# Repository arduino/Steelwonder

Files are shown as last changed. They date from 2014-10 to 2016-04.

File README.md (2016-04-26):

Steelwonder
===========

This is the repository of the 3d printer that where built during a workshop hosted by Arduino LLC at the makerspace STPLN in Malmö, Sweden.

The frame [P3Steel](reprap.org/wiki/P3Steel) is a remix of [Twelvepro's](http://www.thingiverse.com/thing:39889/) redesign of [Josef Prusa's i3](https://github.com/josefprusa/Prusa3-vanilla). There have been some alterations to the frame such as the deletion of the triangles covering the xz frame and some holes for a powersupply and the electronics have been added. Also the printed parts have been borrowed from the box design from the current [Mendel Prusa i3 box design](https://github.com/josefprusa/Prusa3/tree/master/box_frame).

[Here] (http://youtu.be/In_Q6NkX3fs) you can find a video showing how to assemble the frame.

The plastic parts have mostly been sourced from the box design of the main Prusa i3 branch.

The shroud was sourced from [this](http://www.thingiverse.com/thing:165606) made by stratop80, also [available on tinkercad](https://tinkercad.com/things/1gkTvnWGP8F). Although it was revised and only used for inspiration.

The new plastic parts made for this machine:

  The shroud for the fan.
  
  The legs for the screen.

The Extras Folder.

There are some add-ons for the printer in this folder.

The source for the Y-endstop holder for the moving y-carriage can be found here [here] (https://www.youmagine.com/designs/y-endstop-support-for-p3steel) is made by Antonio Navarro.

An alternative to the shroud that was provided during the workshop is found [here] (http://www.thingiverse.com/thing:268372) and is made by Diego García.

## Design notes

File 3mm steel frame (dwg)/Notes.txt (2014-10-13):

The frame is meant to be cut in 3mm steel. 

The Update located in the "POSSIBLE_UPDATE" folder can also be found on thingiverse: http://www.thingiverse.com/thing:463371

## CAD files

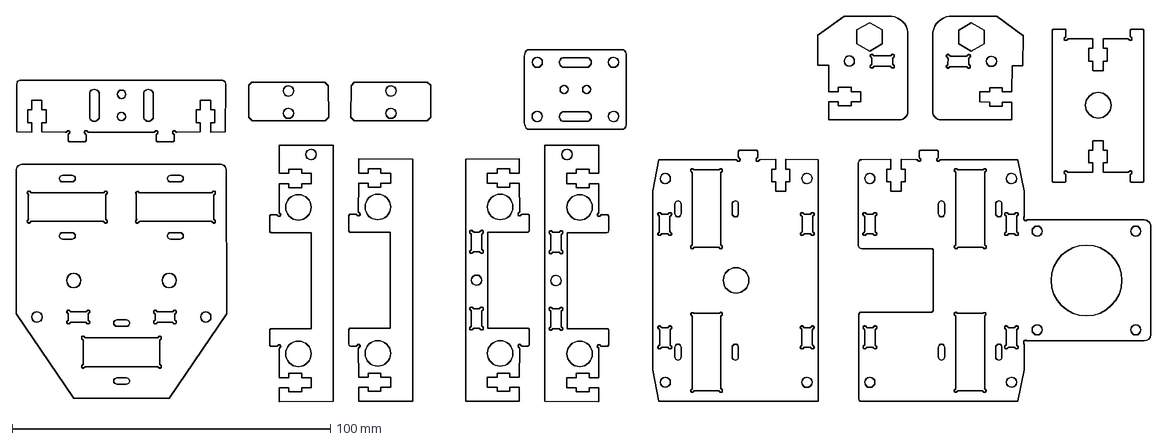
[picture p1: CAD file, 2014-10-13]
3mm steel frame (dwg)/POSSIBBLE_UPDATE/Leonardo_full_metal_cordobesa.dxf
356.4 x 121.1 mm

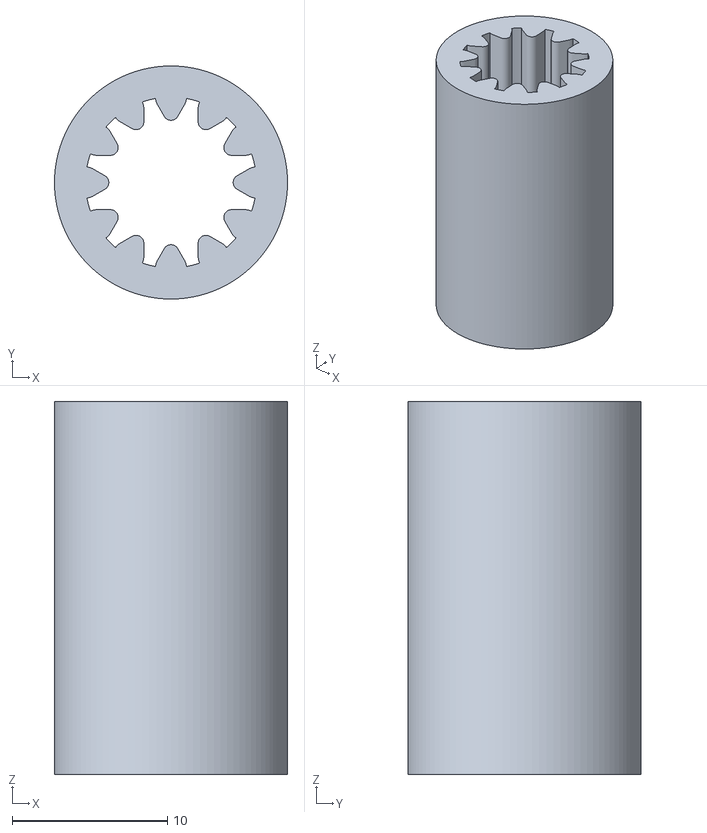
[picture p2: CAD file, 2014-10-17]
plastic parts (source)/OpenSCAD/includes/PrintableBearing_M8.stl
15.0 x 15.0 x 24.0

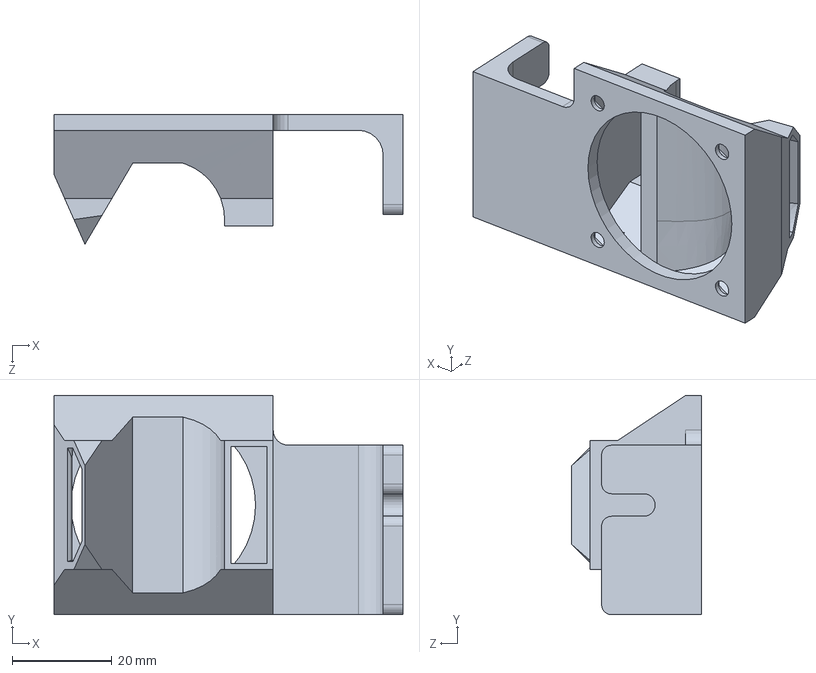
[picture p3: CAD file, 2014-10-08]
plastic parts (source)/Solidworks/Shroud/Shroud for Budaschnozzle.SLDPRT
70.0 x 44.0 x 26.0 mm

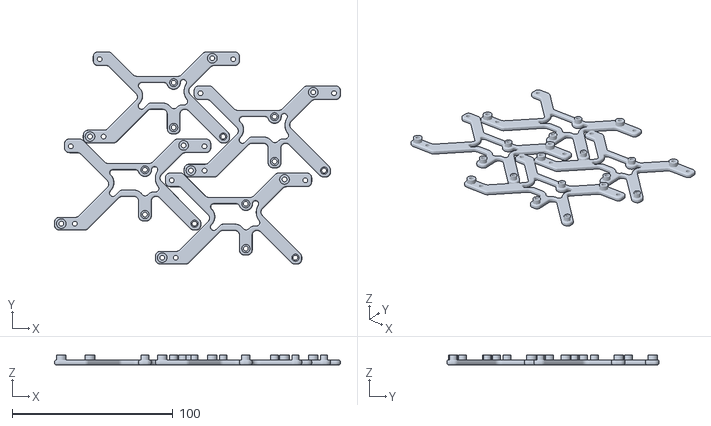
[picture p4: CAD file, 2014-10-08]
Plastic parts (stl)/Extras/Electronicsholder/holder - holder-1.STL
178.2 x 132.2 x 6.00

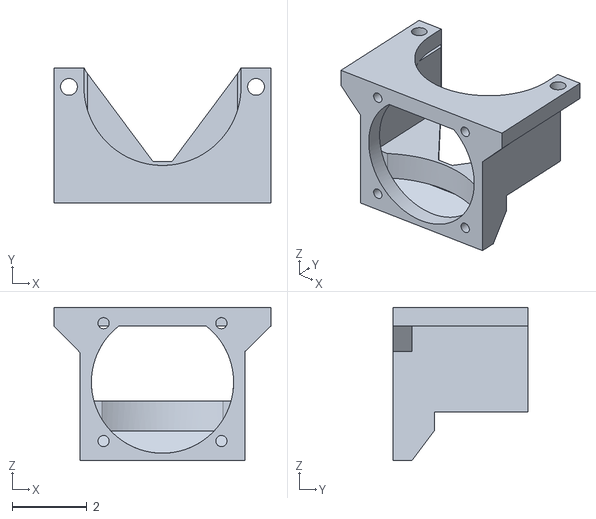
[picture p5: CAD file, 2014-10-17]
Plastic parts (stl)/Extras/Hot-end cooling mechanism/budasnozzle_soporte_ventilador_V2.stl
5.80 x 3.60 x 4.10

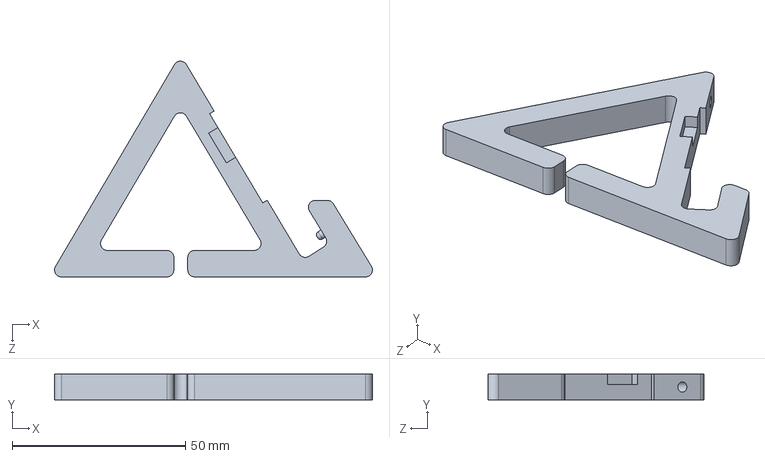
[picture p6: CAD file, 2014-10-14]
Plastic parts (stl)/Screen holder/3angle.SLDPRT
91.9 x 7.50 x 62.4 mm

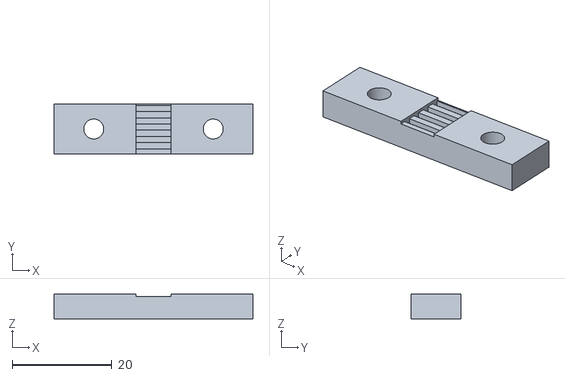
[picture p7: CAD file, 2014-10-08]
Plastic parts (stl)/Y-belt holder/y-holder-back.stl
40.0 x 10.0 x 5.00

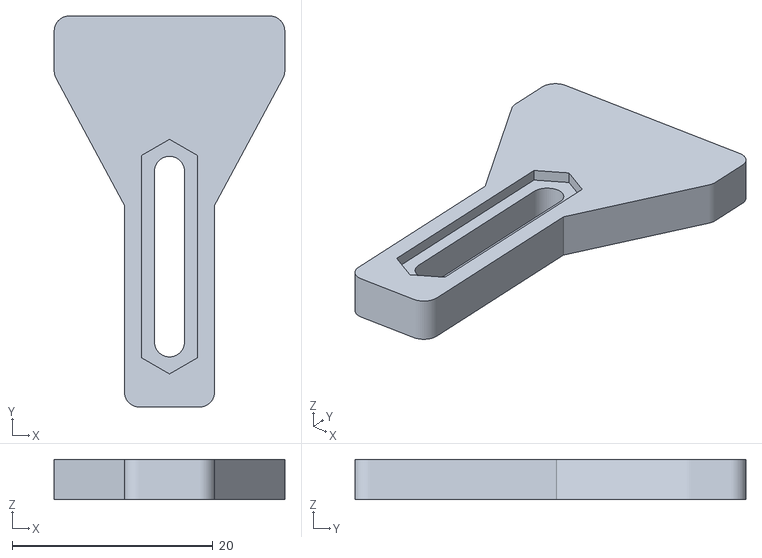
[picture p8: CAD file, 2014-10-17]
Plastic parts (stl)/Y-Endstop holders for y-carriage/P3Steel-Y-EndStop_part1.stl
23.0 x 39.0 x 4.00

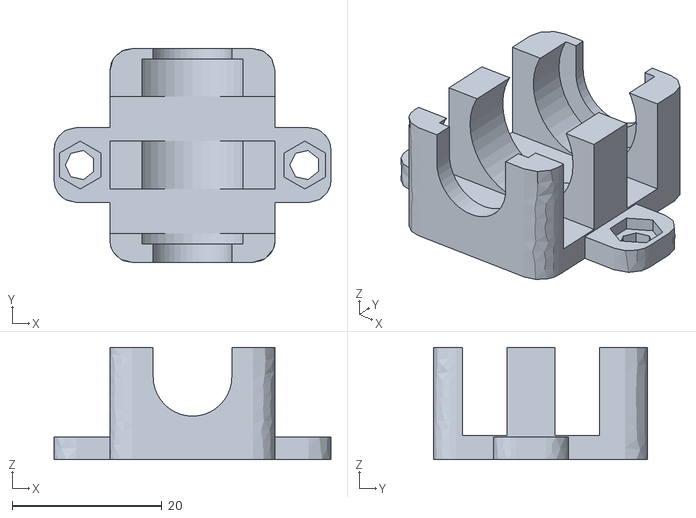
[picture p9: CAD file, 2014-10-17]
plastic parts (source)/OpenSCAD/includes/Pieza_Final (Meshed).stl
37.0 x 28.6 x 15.0

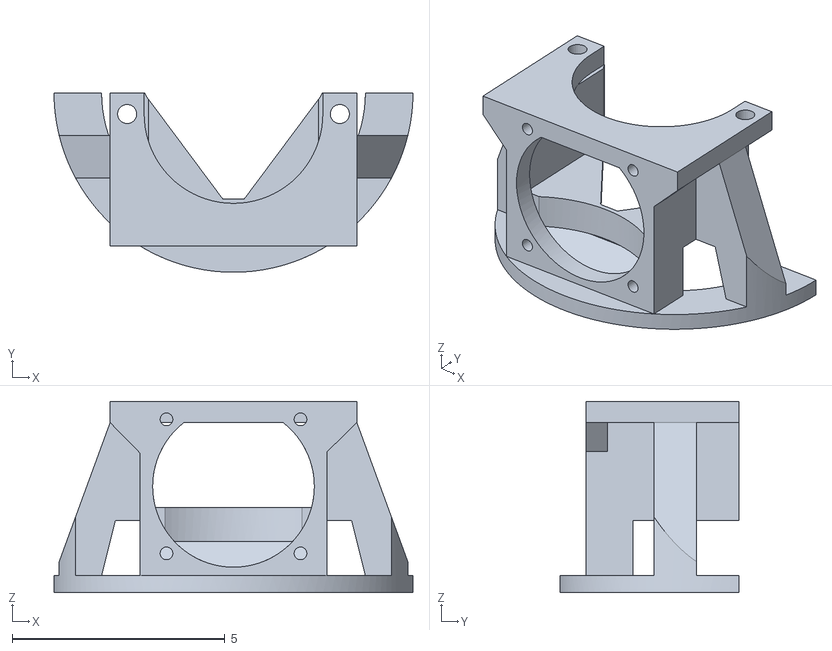
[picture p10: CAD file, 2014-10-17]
Plastic parts (stl)/Extras/Hot-end cooling mechanism/Budas_Ventilador_y_leds.stl
8.44 x 4.22 x 4.50

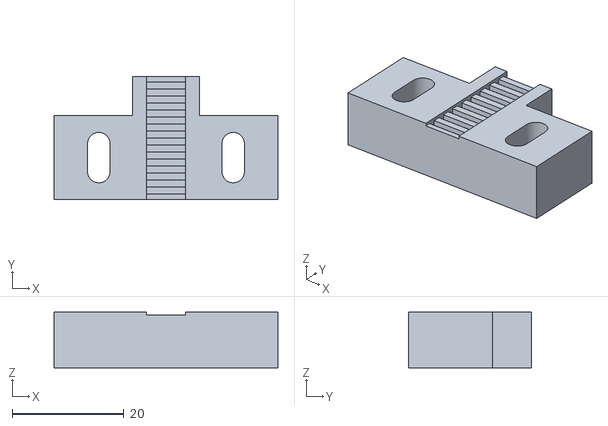
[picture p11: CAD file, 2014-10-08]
Plastic parts (stl)/Y-belt holder/y-holder-front.stl
40.0 x 22.0 x 10.0

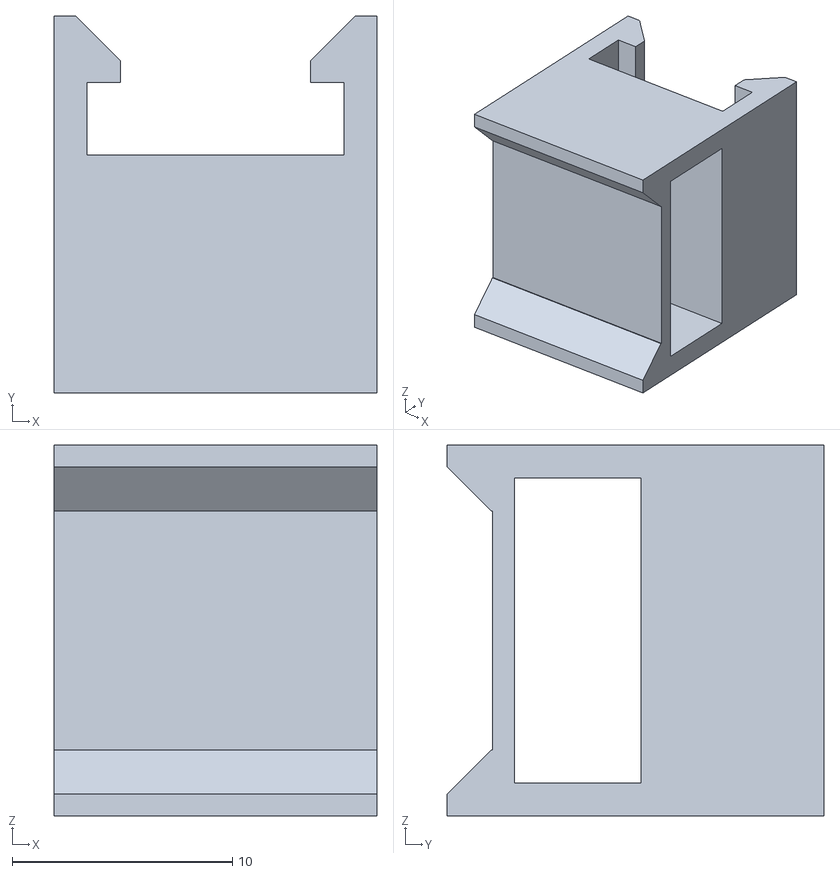
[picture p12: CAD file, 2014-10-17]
Plastic parts (stl)/Y-Endstop holders for y-carriage/P3Steel-Y-EndStop_part2.stl
14.7 x 17.1 x 16.9

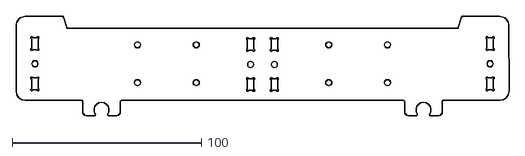
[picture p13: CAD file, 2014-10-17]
plastic parts (source)/OpenSCAD/includes/Frontal_y_Trasero.dxf
260.4 x 52.4

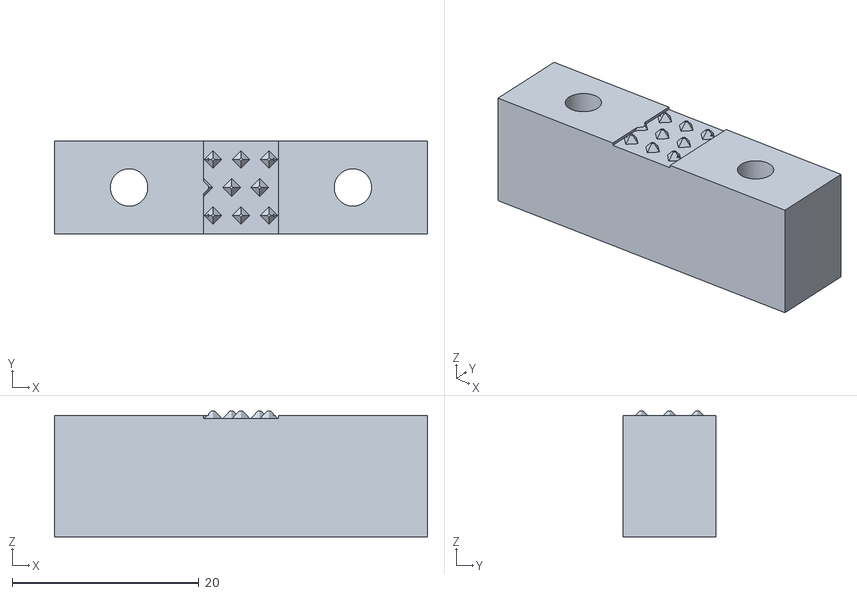
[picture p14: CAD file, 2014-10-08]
Plastic parts (stl)/Y-belt holder/y-holder-support.stl
40.0 x 10.00 x 13.5

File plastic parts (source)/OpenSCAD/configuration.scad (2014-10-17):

// PRUSA iteration3
// Configuration file
// GNU GPL v3
// Josef Průša <josefprusa@me.com>
// Václav 'ax' Hůla <axtheb@gmail.com>
// http://www.reprap.org/wiki/Prusa_Mendel
// http://github.com/josefprusa/Prusa3

include <inc/metric.scad>;
include <inc/conf_bushing.scad>;

// Custom settings here, tailor to your supplies and print settings

// Extruder settings **********************************************************
// Don't forget to set your slicer's extruder settings to match the values you
// enter here.

layer_height = 0.3;
// Width over thickness determines how wide the plastic will be when extruded
// onto the object that is being printed. width_over_thickness is multiplied
// by the layer_height to calculate this width. i.e. If your layer_height is
// set to 0.3 mm and your width_over_thickness is set to 2.2, the resulting
// width will be 0.66 mm.
width_over_thickness = 2.2;

// Select your belt type ******************************************************

// T2.5
//belt_width = 6.5;  //add 0.5 to actual width
//belt_tooth_distance = 2.5;
//belt_tooth_ratio = 0.75;
//belt_thickness = 0.8;

// T5 (strongly discouraged)
//belt_width = 6.5;
//belt_tooth_distance = 5;
//belt_tooth_ratio = 0.75;
//belt_thickness = 0.8;

// HTD3
//belt_width = 9.5;
//belt_tooth_distance = 3;
//belt_tooth_ratio = 0.75;
//belt_thickness = 1.75;

// MXL
//belt_width = 6.5;
//belt_tooth_distance = 2.032;
//belt_tooth_ratio = 0.64;
//belt_thickness = i have no idea;

// GT2 
// there is bunch of GT2 belts with different tooth-to-tooth distance
// this one is most common in reprap world
// adjust to your needs.
belt_width = 6.5;
belt_tooth_distance = 2;
belt_tooth_ratio = 0.5;
belt_thickness = 0.8;

// Choose bearing/bushing configuration ***************************************
// conf_b_* are in inc/conf_bushing.scad

bushing_xy = conf_b_lm8uu;
bushing_z = conf_b_lm8uu;
// for longer bearings use one shorter in x-carriage to make place for belt attachment
// by default use same as xy
bushing_carriage = bushing_xy;


// Select idler bearing size **************************************************
// bearing_* are in inc/conf_bushing.scad

idler_bearing = bearing_625;

// Select carriage lenght ******************************************************
// 30 for single carriage extruder (two holes with centers 30mm apart)
// 50 for wade or single with fan (three holes, 30-20)
// 80 for full length carriage (four holes, 30-20-30)

carriage_l_base = 50;


// Fillets ********************************************************************
// fillets are rounded corners of boxes. The right engineering term is probably radius
// but cad software calls it fillet.
// mostly cosmetic, except z axis.
// 0 = no fillets
// 1 = fillet
// 2 = chamfer (cut the edges at 45deg. angle)
// Please do put only parts with fillets on sale, other options are not really tested

use_fillets = 1;

// set to 0 for single plate (affects z axis and screws that attach RP parts to frame)
i_am_box = 0;

// if you do your own plate and can move bottom Z screws 5mm up set this to 0 to
// get stronger motor mount. Only for i_am_box = 0
i_want_to_use_single_plate_dxf_and_make_my_z_weaker = 1;


// Radius of long threaded rod on Y frame

// Affects y-axis-corner (both box and single plate)
// and y-axis-bracket (box only)

//Use 5.4 for M10 or 4.4 for M8
y_threaded_rod_long_r = 5.4;


// Thickness of the boards that make the box frame.

// in y-axis-corner it governs the height of the corners by adjusting the
// distance between ground and M10 threaded rod. (both box and single plate)

// For box model, the parts that hold Z smooth rod have one hole from front
// and one from side, and this setting makes sure that the screw from side
// is in the center of the plank.

// Use 12 for single plate
// or 20 if you want to use the Y lm8uu holders
// (extras/bearing-holder-single-plate-y)
board_thickness = 12;

// Segments of small holes. some poeple claim that a low value makes them easier to print.
small_hole_segments=7;

// functions
include <inc/functions.scad>;
include <inc/settings.scad>;

// These constants define the geometry of the doc/complete-printer.scad
bed_x_size=225;
bed_y_size=225;
x_smooth_rod_length=380+board_thickness*2;
y_smooth_rod_length=400;
z_smooth_rod_length=320;

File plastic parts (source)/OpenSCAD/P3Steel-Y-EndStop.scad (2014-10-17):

// Author: Antonio Navarro
// URL: http://www.thingiverse.com/AntonioNav/
//
// Licencia: CC BY-SA 3.0
//  http://creativecommons.org/licenses/by-sa/3.0/
//

use <Includes/nuts_and_bolts.scad>
use <Includes/roundCornersCube.scad>

$fn=50;

//***********************************************************//
//***** Use 'to_print_part1' and 'to_print_part2' ***********//
//***** to generate stl files.                    ***********//

//to_show();
to_print();
//to_print_part1(); 
//to_print_part2(); 

module to_show(){
	color("orange"){
		back_support();
		bed();
	}
	color("gray"){
		varillas();
	}
	color("green"){
		translate([35,-2-1.5,19.1])
			rotate([90,0,0])
				stopper();
	translate([35,5.1,30])
		rotate([90,0,0])
			endstop_support();
	}
}

module to_print(){
	to_print_part1();
	translate([30,0,0])
		to_print_part2();	
}

module to_print_part1(){
	translate([0,0,2])
	rotate([0,180,0])
	stopper();
}

module to_print_part2(){
	translate([0,0,(16.85)/2])
		rotate([0,90,0])
			endstop_support();
}

module clamp(long=12.85, alt=3.9){

	translate([-long/2,-2,0])
	union(){
		translate([0,0,alt-0.1])
			difference(){
				cube([long,3,3]);
				translate([-1,4,0])
					rotate([45,0,0])
						cube([long+2,2.5,6]);
			}
		translate([0,0,0])
			cube([long,1.5,alt]);
	}

}

module endstop_support(){
	long=13.85;
	width=5.75;
	alt=6.65;
	sep=14.65;

	union(){
		translate([0,width/2+1,0])
			cube([long+3,2,sep], center=true);
		translate([0,(width+3)/2,sep/2-2])
			rotate([-90,0,0])
				clamp(long+3);
		rotate([0,180,0])
		translate([0,(width+3)/2,sep/2-2])
			rotate([-90,0,0])
				clamp(long+3);

	translate([long/2-0.5,(width+0.1)/2,0])
		rotate([0,-90,90])
			clamp(sep,width+0.2);

	rotate([0,180,0])
	translate([long/2-0.5,(width+0.1)/2,0])
		rotate([0,-90,90])
			clamp(sep,width+0.2);
	
//support for print
	translate([0,-width/2-0.5,0])
		cube([long,1,sep], center=true);
	}

}

module endstop(long=12.85, width=5.75, alt=6.65){
	color("black")
		cube([long,width,alt], center=true);
}


module varillas(){
	translate([85,100,24])
		rotate([90,0,0])
			cylinder(d=8,h=200, center=true);
	translate([-85,100,24])
		rotate([90,0,0])
			cylinder(d=8,h=200, center=true);
}

module stopper(){

		difference(){
			base_square();
			//Taladro tornillo M3
			hull(){
				translate([0,-8,0])
					cylinder(d=3, h=11, center=true);
				translate([0,-25,0])
					cylinder(d=3, h=11, center=true);
			}

/*			hull(){
				translate([0,-8,1])
					cylinder(r=3.2, h=2.4);
				translate([0,-25,1])
					cylinder(r=3.2, h=2.4);
			}
*/
			hull(){
				translate([0,-8,-3.4])
					rotate([0,0,30])
						nutHole(3);
				translate([0,-25,-3.4])
					rotate([0,0,30])
						nutHole(3);
			}
		}
}

module base_square(alt=4, diam=3){
	hull(){
		translate([10,2,0])
				cylinder(d=diam, h=alt, center=true);
		translate([-10,2,0])
				cylinder(d=diam, h=alt, center=true);
		translate([10,6,0])
				cylinder(d=diam, h=alt, center=true);
		translate([-10,6,0])
				cylinder(d=diam, h=alt, center=true);
	}
	hull(){
		translate([10,2,0])
				cylinder(d=diam, h=alt, center=true);
		translate([-10,2,0])
				cylinder(d=diam, h=alt, center=true);
		translate([3,-11,0])
				cylinder(d=diam, h=alt, center=true);
		translate([-3,-11,0])
				cylinder(d=diam, h=alt, center=true);
	}

	hull(){
		translate([3,-11,0])
				cylinder(d=diam, h=alt, center=true);
		translate([-3,-11,0])
				cylinder(d=diam, h=alt, center=true);
		translate([3,-30,0])
				cylinder(d=diam, h=alt, center=true);
		translate([-3,-30,0])
				cylinder(d=diam, h=alt, center=true);
	}
}

module back_support(){
	translate([-140.5,-1.5,32])
			rotate([-90,0,0])
				linear_extrude(height=3)
					import("./Includes/Frontal_y_Trasero.dxf");
}

module bed(){

	translate([0,85,36.5]){
		bed_base();
		bed_supports();
	}
}
	
module bed_base(){

		rotate([0,0,-90])
			translate([-122.5,-109.5,-1.5])
				linear_extrude(height=3)
					import("./Includes/Base_cama.dxf");
}

module bed_supports(){
	translate([85,-35,-1.5])
		rotate([0,180,0])
			rotate([0,0,90]){
				i2_y_bushing();
				translate([-1.5,0,3.5])
				rotate([0,0,90])
					bearing();
		}

	translate([85,35,-1.5])
		rotate([0,180,0])
			rotate([0,0,90]){
				i2_y_bushing();
				translate([-1.5,0,3.5])
				rotate([0,0,90])
					bearing();
		}

	translate([-85,-35,-1.5])
		rotate([0,180,0])
			rotate([0,0,90]){
				i2_y_bushing();
				translate([-1.5,0,3.5])
				rotate([0,0,90])
					bearing();
		}

	translate([-85,35,-1.5])
		rotate([0,180,0])
			rotate([0,0,90]){
				i2_y_bushing();
				translate([-1.5,0,3.5])
				rotate([0,0,90])
					bearing();
		}

}

module i2_y_bushing(){
		rotate([0,0,90])
					import("./Includes/Pieza_Final (Meshed).stl");
}

module bearing(){
	translate([0,0,7.5])
		rotate([90,0,0])
			translate([0,0,-12])
					import("./Includes/PrintableBearing_M8.stl");
}

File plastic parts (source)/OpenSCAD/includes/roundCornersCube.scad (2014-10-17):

/*
http://codeviewer.org/view/code:1b36
Copyright (C) 2011 Sergio Vilches
This program is free software: you can redistribute it and/or modify it under the terms of the GNU General Public License as published by the Free Software Foundation, either version 3 of the License, or (at your option) any later version.
This program is distributed in the hope that it will be useful, but WITHOUT ANY WARRANTY; without even the implied warranty of MERCHANTABILITY or FITNESS FOR A PARTICULAR PURPOSE. See the GNU General Public License for more details. You should have received a copy of the GNU General Public License along with this program. If not, see <http://www.gnu.org/licenses/>.
Contact: s.vilches.e@gmail.com


    -----------------------------------------------------------
                 Round Corners Cube (Extruded)
      roundCornersCube(x,y,z,r) Where:
         - x = Xdir width
         - y = Ydir width
         - z = Height of the cube
         - r = Rounding radious
                                                              
      Example: roundCornerCube(10,10,2,1);
     *Some times it's needed to use F6 to see good results!
  -----------------------------------------------------------
*/
// Test it!
//roundCornersCube(10,5,2,1);
//Be carefull if is too small, reduce radius
//mediumRoundCornersCube(10,5,2,1);
//fullRoundCornersCube(10,5,2,0.6);

module createMeniscus(h,radius) // This module creates the shape that needs to be substracted from a cube to make its corners rounded.
difference(){ //This shape is basicly the difference between a quarter of cylinder and a cube
   translate([radius/2+0.1,radius/2+0.1,0]){
      cube([radius+0.2,radius+0.1,h+0.2],center=true); // All that 0.x numbers are to avoid "ghost boundaries" when substracting
   }

   cylinder(h=h+0.2,r=radius,$fn=100,center=true);
}


module roundCornersCube(x,y,z,r) // Now we just substract the shape we have created in the four corners
difference(){
  cube([x,y,z], center=true);

	translate([x/2-r,y/2-r]){ // We move to the first corner (x,y)
      rotate(0){
         createMeniscus(z,r); // And substract the meniscus
      }
   }
	translate([-x/2+r,y/2-r]){ // To the second corner (-x,y)
      rotate(90){
         createMeniscus(z,r); // But this time we have to rotate the meniscus 90 deg
      }
   }
	translate([-x/2+r,-y/2+r]){ // ...
      rotate(180){
         createMeniscus(z,r);
      }
   }
	translate([x/2-r,-y/2+r]){
      rotate(270){
         createMeniscus(z,r);
      }
   }
}

module mediumRoundCornersCube(x,y,z,r){

	difference(){
		roundCornersCube(x,y,z,r);
		//Mas lados
		translate([x/2-r,0,(z/2-r)]){
     	 rotate([90,0,0]){
       	  createMeniscus(y,r);
      	}
   	}
		translate([x/2-r,0,-(z/2-r)]){
      rotate([-90,0,0]){
         createMeniscus(y,r);
      }
   	}
		translate([-x/2+r,0,-(z/2-r)]){
			rotate([0,90,0])
				rotate([-90,0,0]){
         		createMeniscus(y,r);
			}
   	}
		translate([-x/2+r,0,(z/2-r)]){
			rotate([0,180,0])
				rotate([-90,0,0]){
         		createMeniscus(y,r);
      	}
   	}
	}
}

module fullRoundCornersCube(x,y,z,r){

	difference(){
		mediumRoundCornersCube(x,y,z,r);
		//Mas lados
		translate([0,y/2-r,(z/2-r)])
			rotate([0,-90,0])
				createMeniscus(x,r);
		translate([0,-y/2+r,(z/2-r)])
			rotate([90,0,0])
				rotate([0,-90,0])
					createMeniscus(x,r);
		translate([0,y/2-r,(-z/2+r)])
			rotate([0,90,0])
				createMeniscus(x,r);
		translate([0,-y/2+r,(-z/2+r)])
			rotate([180,0,0])
				rotate([0,-90,0])
					createMeniscus(x,r);
	}
}

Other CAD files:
3mm steel frame (dwg)/metal_3mm.DWG
Plastic parts (stl)/Fan shroud/Shroud for 40mm fan.STL
Plastic parts (stl)/Extras/Electronicsholder/holder.SLDPRT
plastic parts (source)/OpenSCAD/includes/Base_cama.dxf
plastic parts (source)/OpenSCAD/inc/settings.scad
Plastic parts (stl)/Screen holder/3angle.STL
plastic parts (source)/OpenSCAD/bushing.scad
plastic parts (source)/OpenSCAD/extras/bearing-holder-single-plate-y.scad
plastic parts (source)/OpenSCAD/extras/calibrate.scad
plastic parts (source)/OpenSCAD/extras/endstop-holder-extra.scad
plastic parts (source)/OpenSCAD/extras/endstop-holder.scad
plastic parts (source)/OpenSCAD/extras/foldingclamp.scad
plastic parts (source)/OpenSCAD/extras/gregs-wade-v3.scad
plastic parts (source)/OpenSCAD/extras/groovemount.scad
plastic parts (source)/OpenSCAD/extras/inc/parametric_involute_gear_v5.0.scad
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

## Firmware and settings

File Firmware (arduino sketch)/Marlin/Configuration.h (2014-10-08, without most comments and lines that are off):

#define CONFIGURATION_H
#define STRING_VERSION_CONFIG_H __DATE__ " " __TIME__ // build date and time
#define STRING_CONFIG_H_AUTHOR "(none, default config)" // Who made the changes.
#define SERIAL_PORT 0
#define BAUDRATE 115200 //Transfer rate with USB
#define MOTHERBOARD 33
#define CUSTOM_MENDEL_NAME "Korken"
#define EXTRUDERS 1
#define POWER_SUPPLY 1
#define TEMP_SENSOR_0 1
#define TEMP_SENSOR_1 0
#define TEMP_SENSOR_2 0
#define TEMP_SENSOR_BED 1
#define MAX_REDUNDANT_TEMP_SENSOR_DIFF 10
#define TEMP_RESIDENCY_TIME 10  // (seconds)
#define TEMP_HYSTERESIS 3       // (degC) range of +/- temperatures considered "close" to the target one
#define TEMP_WINDOW     1       // (degC) Window around target to start the residency timer x degC early.
#define HEATER_0_MINTEMP 5
#define HEATER_1_MINTEMP 5
#define HEATER_2_MINTEMP 5
#define BED_MINTEMP 5
#define HEATER_0_MAXTEMP 275 //PLA 180-220 ,ABS 225 - 240
#define HEATER_1_MAXTEMP 275
#define HEATER_2_MAXTEMP 275
#define BED_MAXTEMP 120
#define PIDTEMP
#define BANG_MAX 255 // limits current to nozzle while in bang-bang mode; 255=full current
#define PID_MAX 255 // limits current to nozzle while PID is active (see PID_FUNCTIONAL_RANGE below); 255=full current
  #define PID_FUNCTIONAL_RANGE 10 // If the temperature difference between the target temperature and the actual temperature
  #define PID_INTEGRAL_DRIVE_MAX 255  //limit for the integral term
  #define K1 0.95 //smoothing factor within the PID
  #define PID_dT ((OVERSAMPLENR * 8.0)/(F_CPU / 64.0 / 256.0)) //sampling period of the temperature routine
  #define DEFAULT_Kp 14.94
  #define DEFAULT_Ki 1.53
  #define DEFAULT_Kd 36.47
#define MAX_BED_POWER 255 // limits duty cycle to bed; 255=full current
#define PREVENT_DANGEROUS_EXTRUDE
#define PREVENT_LENGTHY_EXTRUDE
#define EXTRUDE_MINTEMP 170
#define EXTRUDE_MAXLENGTH (X_MAX_LENGTH+Y_MAX_LENGTH) //prevent extrusion of very large distances.
#define ENDSTOPPULLUPS // Comment this out (using // at the start of the line) to disable the endstop pullup resistors
  #define ENDSTOPPULLUP_XMAX
  #define ENDSTOPPULLUP_YMAX
  #define ENDSTOPPULLUP_ZMAX
  #define ENDSTOPPULLUP_XMIN
  #define ENDSTOPPULLUP_YMIN
  #define ENDSTOPPULLUP_ZMIN
const bool X_MIN_ENDSTOP_INVERTING = true; // set to true to invert the logic of the endstop.
const bool Y_MIN_ENDSTOP_INVERTING = true; // set to true to invert the logic of the endstop.
const bool Z_MIN_ENDSTOP_INVERTING = true; // set to true to invert the logic of the endstop.
const bool X_MAX_ENDSTOP_INVERTING = true; // set to true to invert the logic of the endstop.
const bool Y_MAX_ENDSTOP_INVERTING = true; // set to true to invert the logic of the endstop.
const bool Z_MAX_ENDSTOP_INVERTING = true; // set to true to invert the logic of the endstop.
#if defined(COREXY) && !defined(DISABLE_MAX_ENDSTOPS)
  #define DISABLE_MAX_ENDSTOPS
#endif
#define X_ENABLE_ON 0
#define Y_ENABLE_ON 0
#define Z_ENABLE_ON 0
#define E_ENABLE_ON 0 // For all extruders
#define DISABLE_X false
#define DISABLE_Y false
#define DISABLE_Z false
#define DISABLE_E false // For all extruders
#define DISABLE_INACTIVE_EXTRUDER true //disable only inactive extruders and keep active extruder enabled
#define INVERT_X_DIR true    // for Mendel set to false, for Orca set to true
#define INVERT_Y_DIR false    // for Mendel set to true, for Orca set to false
#define INVERT_Z_DIR true     // for Mendel set to false, for Orca set to true
#define INVERT_E0_DIR false   // for direct drive extruder v9 set to true, for geared extruder set to false
#define INVERT_E1_DIR false    // for direct drive extruder v9 set to true, for geared extruder set to false
#define INVERT_E2_DIR false   // for direct drive extruder v9 set to true, for geared extruder set to false
#define X_HOME_DIR -1
#define Y_HOME_DIR -1
#define Z_HOME_DIR -1
#define min_software_endstops true // If true, axis won't move to coordinates less than HOME_POS.
#define max_software_endstops true  // If true, axis won't move to coordinates greater than the defined lengths below.
#define X_MAX_POS 205
#define X_MIN_POS 0
#define Y_MAX_POS 205
#define Y_MIN_POS 0
#define Z_MAX_POS 200
#define Z_MIN_POS 0
#define X_MAX_LENGTH (X_MAX_POS - X_MIN_POS)
#define Y_MAX_LENGTH (Y_MAX_POS - Y_MIN_POS)
#define Z_MAX_LENGTH (Z_MAX_POS - Z_MIN_POS)
#define MANUAL_X_HOME_POS 0
#define MANUAL_Y_HOME_POS 0
#define MANUAL_Z_HOME_POS 0
#define NUM_AXIS 4 // The axis order in all axis related arrays is X, Y, Z, E
#define HOMING_FEEDRATE { 1000, 1000, 100, 45 }  // set the homing speeds (mm/min)
#define DEFAULT_AXIS_STEPS_PER_UNIT   {80,80,4000, 755}  // default steps per unit for Ultimaker
#define DEFAULT_MAX_FEEDRATE          {500, 500, 3, 25}    // (mm/sec)
#define DEFAULT_MAX_ACCELERATION      {4000,4000,50,500}    // X, Y, Z, E maximum start speed for accelerated moves. E default values are good for Skeinforge 40+, for older versions raise them a lot.
#define DEFAULT_ACCELERATION          3000    // X, Y, Z and E max acceleration in mm/s^2 for printing moves
#define DEFAULT_RETRACT_ACCELERATION  3000   // X, Y, Z and E max acceleration in mm/s^2 for retracts
#define DEFAULT_XYJERK                20.0    // (mm/sec)
#define DEFAULT_ZJERK                 0.3     // (mm/sec)
#define DEFAULT_EJERK                 5.0    // (mm/sec)
#define CUSTOM_M_CODES
  #define CUSTOM_M_CODE_SET_Z_PROBE_OFFSET 851
  #define Z_PROBE_OFFSET_RANGE_MIN -15
  #define Z_PROBE_OFFSET_RANGE_MAX -5
#define PLA_PREHEAT_HOTEND_TEMP 180
#define PLA_PREHEAT_HPB_TEMP 70
#define PLA_PREHEAT_FAN_SPEED 255   // Insert Value between 0 and 255
#define ABS_PREHEAT_HOTEND_TEMP 230
#define ABS_PREHEAT_HPB_TEMP 100
#define ABS_PREHEAT_FAN_SPEED 255   // Insert Value between 0 and 255
#define G3D_PANEL
 #define ULTIPANEL
 #define NEWPANEL
  #define SDSUPPORT
  #define ULTRA_LCD
    #define LCD_WIDTH 20
    #define LCD_HEIGHT 4
#define SOFT_PWM_SCALE 0
#include "Configuration_adv.h"
#include "thermistortables.h"

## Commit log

2014-10-08 Firmware + y belt holder
    [Configuration.h, Configuration_adv.h, y-holder-back.stl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]
2014-10-08 Firmware and stl's
    [Configuration.h, Configuration_adv.h, Shroud.STL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]
2014-10-08 FaFan shroud and Holder for electronics added
    [Shroud.SLDPRT, Shroud.STL, holder - holder-1.STL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]
2014-10-13 Uploaded files for Frame and updated frame
    [Leonardo_full_metal_cordobesa.dxf, metal_3mm.DWG]
2014-10-14 screen holder
    [3angle.SLDPRT, 3angle.STL, holder - trimpot_nob-1.STL]
2014-10-17 Source files for plastic parts added
    Added sources and extrasfor printer. Like y-endstops.
    [Base_cama.dxf, Frontal_y_Trasero.dxf, P3Steel-Y-EndStop.scad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]
2014-10-17 update to a bunch of files
    Extras and more....
    [Budas_Ventilador_y_leds.stl, P3Steel-Y-EndStop_part1.stl, P3Steel-Y-EndStop_part2.stl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]
